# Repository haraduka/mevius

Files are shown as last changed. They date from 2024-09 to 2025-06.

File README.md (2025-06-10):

# MEVIUS
This repository includes the hardware and software components of "MEVIUS: A Quadruped Robot Easily Constructed through E-Commerce with Sheet Metal Welding and Machining."

Please refer to the following links for more information.
- [Project Page](https://haraduka.github.io/mevius-hardware)
- [arXiv](https://arxiv.org/abs/2409.14721)
- [YouTube](https://www.youtube.com/watch?v=XXJ4EK3Y4zQ)

# Hardware

You can find all the hardware components in the following link
- [Goodle Drive](https://drive.google.com/drive/folders/18i6CWtUG8fkY0rCcbjN5WiUYItjIX0WM?usp=sharing)

From the link of RUBIK LINK V2.0, please download the upper computer installation program and make all the motors MIT mode.
- [AK70-10](https://www.cubemars.com/goods-1031-AK70-10.html)
- [AK Serials Manual](https://www.cubemars.com/images/file/20241217/1734428582786471.pdf)
- [RUBIK LINK V2.0](https://www.cubemars.com/goods-1140-RUBIK+LINK+V20.html)
- Motor Order: FR(1-3) --> FL(4-6) --> BR(7-9) --> BL(10-12) / Proximal --> Distal
- Link Name: FR_scapula_link --> FR_thigh_link --> FR_calf_link
- Joint Name: FR_collar --> FR_hip --> FR_knee

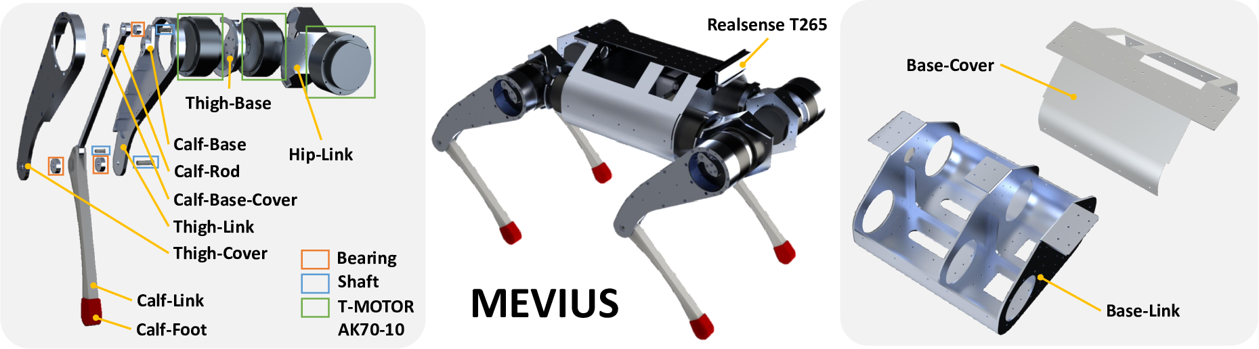
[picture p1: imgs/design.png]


# Software Dependencies
Please install the following dependencies.
- [ROS](https://www.ros.org/)
- [realsense-ros](https://github.com/IntelRealSense/realsense-ros/tree/ros1-legacy)
- [spacenav_node](https://wiki.ros.org/spacenav_node) # optional
- [virtual_joystick](https://github.com/aquahika/rqt_virtual_joystick) # optional
- [urdfdom-py](https://github.com/ros/urdf_parser_py)
- [legged_gym](https://github.com/leggedrobotics/legged_gym)

Please install the following python packages.
- bitstring
- pytorch
- scipy
- mujoco
- mujoco-python-viewer

# Build
```
mkdir -p ~/mevius_ws/src
cd ~/mevius_ws/src
git clone git@github.com:haraduka/mevius.git
cd ..
catkin build
source ~/mevius_ws/devel/setup.bash
```

# Reinforcement Learning
Caution: This policy is very simple and not so stable. Currently, it became very stable with a lot of improvement and will be uploaded soon.

```
# in legged_gym
git remote add haraduka git@github.com:haraduka/legged_gym.git
git fetch haraduka
git checkout haraduka/mevius

# train with two phases
# first phase
python3 legged_gym/scripts/train.py --task mevius
# second phase
# change the parameters in legged_gym/envs/mevius/mevius_config.py from "first" to "second"
# there are two parameters to change: commands.ranges and domain_rand.friction_range
python3 legged_gym/scripts/train.py --task mevius
python3 legged_gym/scripts/play.py --task mevius --load_run ( log_dir )
cp logs/flat_mevius/( log_dir )/exported/policies/policy_1.pt ../mevius/models/policy.pt

```

# Usage
Please test the installation by running the following command.
```
python3 scripts/mevius_utils.py
```
Please test the motors by running the following command.
```
./bin/can_setup.sh
python scripts/tmotor_test.py --ids 1 --task sense
```
Please test the real robot by running the following command.
```
# in the PC of MEVIUS
roscore
roslaunch realsense2_camera rs_t265.launch
./bin/can_setup.sh
python3 scripts/mevius_main.py

# in your local PC
roslaunch spacenav_node classic.launch

# Left Click: SITDOWN/STANDUP, Right Click: STANDUP/WALK

# if you want to simulate the robot in mujoco
python3 scripts/mevius_main.py --sim

# please press D to turn off every-step rendering in mujoco viewer
```

# Acknowledgements
- scripts/tmotor_lib.py is from [mini-cheetah-tmotor-python-can](https://github.com/dfki-ric-underactuated-lab/mini-cheetah-tmotor-python-can)
- scripts/isaacgym_torch_utils.py is from [IsaacGym](https://developer.nvidia.com/isaac-gym)
- scripts/legged_gym_math.py is from [LeggedGym](https://github.com/leggedrobotics/legged_gym)

# Citation
```
@inproceedings{kawaharazuka2024mevius,
  author={K. Kawaharazuka and S. Inoue and T. Suzuki and S. Yuzaki and S. Sawaguchi and K. Okada and M. Inaba},
  title={{MEVIUS: A Quadruped Robot Easily Constructed through E-Commerce with Sheet Metal Welding and Machining}},
  booktitle={Proceedings of the 2024 IEEE-RAS International Conference on Humanoid Robots},
  year=2024,
}
```

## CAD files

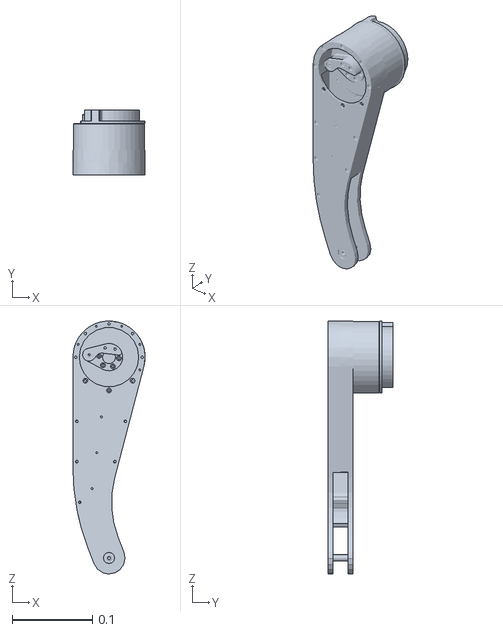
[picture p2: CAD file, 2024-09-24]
models/meshes/BR_thigh_link.STL
0.09 x 0.0811 x 0.315

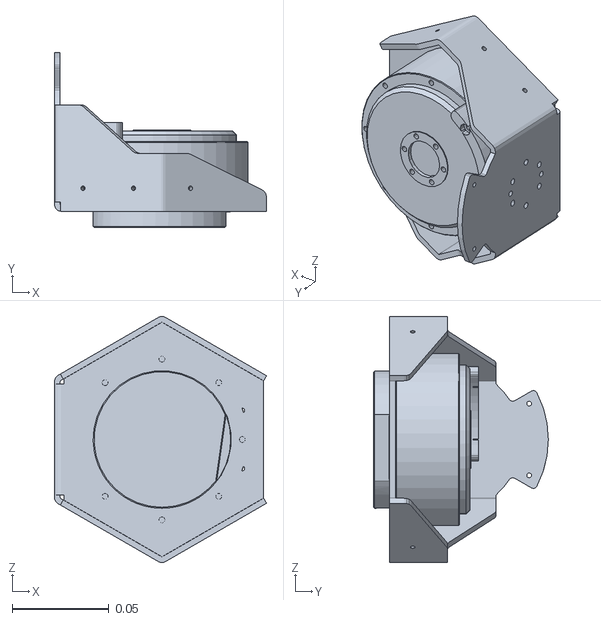
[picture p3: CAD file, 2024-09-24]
models/meshes/FL_scapula_link.STL
0.109 x 0.0902 x 0.127

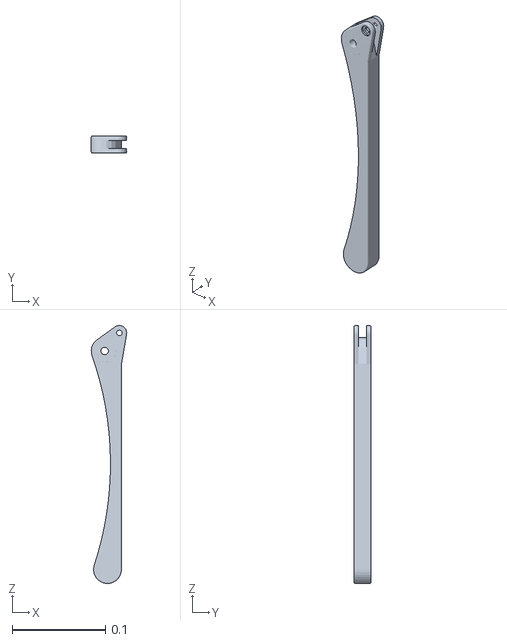
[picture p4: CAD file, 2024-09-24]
models/meshes/BL_calf_link.STL
0.0382 x 0.018 x 0.277

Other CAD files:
models/meshes/BL_thigh_link.STL
models/meshes/FR_scapula_link.STL
models/meshes/BR_scapula_link.STL
models/meshes/FR_thigh_link.STL
models/meshes/BL_scapula_link.STL
models/meshes/FL_thigh_link.STL

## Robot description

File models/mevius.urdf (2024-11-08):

<?xml version="1.0" encoding="utf-8"?>
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
<robot name="mevius">
  <link name="base_link">
    <inertial>
      <origin xyz="-0.00288686344144184 0.0 0.0628887711129525" rpy="0 0 0" />
      <mass value="8.0" />
      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
    </inertial>
    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
  </link>
  <link name="FR_scapula_link">
    <inertial>
      <origin xyz="0.0516252305401659 0.0119000363955649 0.000134643082608681" rpy="0 0 0" />
      <mass value="0.79238908220585" />
      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
    </inertial>
    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
  </link>
  <joint name="FR_collar" type="revolute">
    <origin xyz="0.16405000000001 -0.0720000000000002 0.056500000000002" rpy="0 0 0" />
    <parent link="base_link" />
    <child link="FR_scapula_link" />
    <axis xyz="1 0 0" />
    <limit lower="-0.7854" upper="0.7854" effort="25" velocity="310" />
  </joint>
  <link name="FR_thigh_link">
    <inertial>
      <origin xyz="-0.00458315732717235 -0.0450237251724228 -0.0462116341919131" rpy="0 0 0" />
      <mass value="1.28036049228712" />
      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
    </inertial>
    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
  </link>
  <joint name="FR_hip" type="revolute">
    <origin xyz="0.0555000000000021 -0.01205000000001 0" rpy="0 0 0" />
    <parent link="FR_scapula_link" />
    <child link="FR_thigh_link" />
    <axis xyz="0 1 0" />
    <limit lower="0.0" upper="1.5708" effort="25" velocity="310" />
  </joint>
  <link name="FR_calf_link">
    <inertial>
      <origin xyz="0.00539418153839358 5.12554836518131E-06 -0.108191288731219" rpy="0 0 0" />
      <mass value="0.101512760080133" />
      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
    </inertial>
    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
  </link>
  <joint name="FR_knee" type="revolute">
    <origin xyz="0 -0.06555000000001 -0.250000000000004" rpy="0 0 0" />
    <parent link="FR_thigh_link" />
    <child link="FR_calf_link" />
    <axis xyz="0 1 0" />
    <dynamics damping="0" friction="0"/>
    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
    <limit lower="-2.8745" upper="-1.08" effort="25" velocity="310" />
  </joint>
  <link name="FR_foot_link">
    <inertial>
      <origin xyz="0 0 0" rpy="0 0 0" />
      <mass value="0.05" />
      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
    </inertial>
    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
  </link>
  <joint name="FR_ankle_joint" type="fixed" dont_collapse="true">
    <origin xyz="0.003 0.0 -0.235" rpy="0 0 0"/>
    <parent link="FR_calf_link"/>
    <child link="FR_foot_link"/>
  </joint>

  <link name="FL_scapula_link">
    <inertial>
      <origin xyz="0.0516252305401659 -0.0119000363955649 0.000134643082608681" rpy="0 0 0" />
      <mass value="0.79238908220585" />
      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
    </inertial>
    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
  </link>
  <joint name="FL_collar" type="revolute">
    <origin xyz="0.16405000000001 0.0720000000000002 0.056500000000002" rpy="0 0 0" />
    <parent link="base_link" />
    <child link="FL_scapula_link" />
    <axis xyz="1 0 0" />
    <limit lower="-0.7854" upper="0.7854" effort="25" velocity="310" />
  </joint>
  <link name="FL_thigh_link">
    <inertial>
      <origin xyz="-0.00458315732717235 0.0450237251724228 -0.0462116341919131" rpy="0 0 0" />
      <mass value="1.28036049228712" />
      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
    </inertial>
    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
  </link>
  <joint name="FL_hip" type="revolute">
    <origin xyz="0.0555000000000021 0.01205000000001 0" rpy="0 0 0" />
    <parent link="FL_scapula_link" />
    <child link="FL_thigh_link" />
    <axis xyz="0 1 0" />
    <limit lower="0.0" upper="1.5708" effort="25" velocity="310" />
  </joint>
  <link name="FL_calf_link">
    <inertial>
      <origin xyz="0.00539418153839358 5.12554836518131E-06 -0.108191288731219" rpy="0 0 0" />
      <mass value="0.101512760080133" />
      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
    </inertial>
    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
  </link>
  <joint name="FL_knee" type="revolute">
    <origin xyz="0 0.06555000000001 -0.250000000000004" rpy="0 0 0" />
    <parent link="FL_thigh_link" />
    <child link="FL_calf_link" />
    <axis xyz="0 1 0" />
    <dynamics damping="0" friction="0"/>
    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
    <limit lower="-2.8745" upper="-1.08" effort="25" velocity="310" />
  </joint>
  <link name="FL_foot_link">
    <inertial>
      <origin xyz="0 0 0" rpy="0 0 0" />
      <mass value="0.05" />
      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
    </inertial>
    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
  </link>
  <joint name="FL_ankle_joint" type="fixed" dont_collapse="true">
    <origin xyz="0.003 0.0 -0.235" rpy="0 0 0"/>
    <parent link="FL_calf_link"/>
    <child link="FL_foot_link"/>
  </joint>
  <link name="BR_scapula_link">
    <inertial>
      <origin xyz="-0.051625 0.0119 -0.00013464" rpy="0 0 0" />
      <mass value="0.79239" />
      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
    </inertial>
    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
  </link>
  <joint name="BR_collar" type="revolute">
    <origin xyz="-0.16405000000001 -0.0719999999999995 0.0565000000000019" rpy="0 0 0" />
    <parent link="base_link" />
    <child link="BR_scapula_link" />
    <axis xyz="1 0 0" />
    <limit lower="-0.7854" upper="0.7854" effort="25" velocity="310" />
  </joint>
  <link name="BR_thigh_link">
    <inertial>
      <origin xyz="-0.0038406 -0.045024 -0.046019" rpy="0 0 0" />
      <mass value="1.28036049228712" />
      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
    </inertial>
    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
  </link>
  <joint name="BR_hip" type="revolute">
    <origin xyz="-0.0555000000000055 -0.01205000000001 0" rpy="0 0 0" />
    <parent link="BR_scapula_link" />
    <child link="BR_thigh_link" />
    <axis xyz="0 1 0" />
    <limit lower="0.0" upper="1.5708" effort="25" velocity="310" />
  </joint>
  <link name="BR_calf_link">
    <inertial>
      <origin xyz="0.00539418153839397 5.12554836515355E-06 -0.108191288731218" rpy="0 0 0" />
      <mass value="0.101512760080133" />
      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
    </inertial>
    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
  </link>
  <joint name="BR_knee" type="revolute">
    <origin xyz="0 -0.06555 -0.25" rpy="0 0 0" />
    <parent link="BR_thigh_link" />
    <child link="BR_calf_link" />
    <axis xyz="0 1 0" />
    <dynamics damping="0" friction="0"/>
    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
    <limit lower="-2.8745" upper="-1.08" effort="25" velocity="310" />
  </joint>
  <link name="BR_foot_link">
    <inertial>
      <origin xyz="0 0 0" rpy="0 0 0" />
      <mass value="0.05" />
      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
    </inertial>
    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
  </link>
  <joint name="BR_ankle_joint" type="fixed" dont_collapse="true">
    <origin xyz="0.003 0.0 -0.235" rpy="0 0 0"/>
    <parent link="BR_calf_link"/>
    <child link="BR_foot_link"/>
  </joint>
  <link name="BL_scapula_link">
    <inertial>
      <origin xyz="-0.0516252305401659 -0.0119000363955648 -0.000157365462420601" rpy="0 0 0" />
      <mass value="0.792389082205849" />
      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
    </inertial>
    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
  </link>
  <joint name="BL_collar" type="revolute">
    <origin xyz="-0.16405000000001 0.0719999999999999 0.0564999653300497" rpy="0 0 0" />
    <parent link="base_link" />
    <child link="BL_scapula_link" />
    <axis xyz="1 0 0" />
    <limit lower="-0.7854" upper="0.7854" effort="25" velocity="310" />
  </joint>
  <link name="BL_thigh_link">
    <inertial>
      <origin xyz="-0.00390161717030679 0.0450237251724227 -0.0460663202075131" rpy="0 0 0" />
      <mass value="1.28036049228712" />
      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
    </inertial>
    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
  </link>
  <joint name="BL_hip" type="revolute">
    <origin xyz="-0.0555000000000055 0.01205000000001 0" rpy="0 0 0" />
    <parent link="BL_scapula_link" />
    <child link="BL_thigh_link" />
    <axis xyz="0 1 0" />
    <limit lower="0.0" upper="1.5708" effort="25" velocity="310" />
  </joint>
  <link name="BL_calf_link">
    <inertial>
      <origin xyz="0.00539418153839397 5.12554836515355E-06 -0.108191288731218" rpy="0 0 0" />
      <mass value="0.101512760080133" />
      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
    </inertial>
    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
  </link>
  <joint name="BL_knee" type="revolute">
    <origin xyz="0 0.06555 -0.25" rpy="0 0 0" />
    <parent link="BL_thigh_link" />
    <child link="BL_calf_link" />
    <axis xyz="0 1 0" />
    <dynamics damping="0" friction="0"/>
    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
    <limit lower="-2.8745" upper="-1.08" effort="25" velocity="310" />
  </joint>
  <link name="BL_foot_link">
    <inertial>
      <origin xyz="0 0 0" rpy="0 0 0" />
      <mass value="0.05" />
      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
    </inertial>
    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
  </link>
  <joint name="BL_ankle_joint" type="fixed" dont_collapse="true">
    <origin xyz="0.003 0.0 -0.235" rpy="0 0 0"/>
    <parent link="BL_calf_link"/>
    <child link="BL_foot_link"/>
  </joint>
</robot>

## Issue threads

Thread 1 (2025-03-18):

Proposal for release of 3d-printable parts data in STEP format.

shiba-8ro, 2025-03-18:
The 3d-printable parts of MEVIUS are only available in STL format.
I propose to release them in STEP as well, for improvement.
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

haraduka, 2025-03-19:
Thank you for your proposal.
I released STEP files of 3d-printable parts in google drive.

Also, I newly added an assembled STEP file for easier reproduction.

Closed 2025-03-19.

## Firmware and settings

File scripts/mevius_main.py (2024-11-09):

import argparse
import os
import sys
import select
import time
import threading
import numpy as np

import rospy
from scipy.spatial.transform import Rotation
from std_msgs.msg import String, Float32MultiArray
from sensor_msgs.msg import Imu, Joy, JointState
from nav_msgs.msg import Odometry
from tmotor_lib import CanMotorController
from mevius.msg import MeviusLog
import mevius_utils
import parameters as P

# TODO add terminal display of thermometer, etc.

np.set_printoptions(precision=3)

class RobotState:
    def __init__(self, n_motor=12):
        self.angle = [0.0] * n_motor
        self.velocity = [0.0] * n_motor
        self.current = [0.0] * n_motor
        self.temperature = [0.0] * n_motor
        self.lock = threading.Lock()

class PeripheralState:
    def __init__(self):
        self.realsense_last_time = None
        self.body_vel = [0.0] * 3
        self.body_quat = [0.0] * 4
        self.body_gyro = [0.0] * 3
        self.body_acc = [0.0] * 3
        self.spacenav_enable = False
        self.spacenav = [0.0] * 8
        self.virtual_enable = False
        self.virtual = [0.0] * 4
        self.lock = threading.Lock()

class RobotCommand:
    def __init__(self, n_motor=12):
        self.angle = [0.0] * n_motor
        self.velocity = [0.0] * n_motor
        self.kp = []
        self.kd = []
        self.coef = 1.0
        for name in P.JOINT_NAME:
            for key in P.control.stiffness.keys():
                if key in name:
                    self.kp.append(P.control.stiffness[key]*self.coef)
                    self.kd.append(P.control.damping[key]*self.coef)
        assert len(self.kp) == n_motor
        assert len(self.kd) == n_motor
        self.torque = [0.0] * n_motor

        self.command = "STANDBY"
        self.initial_angle = [0.0] * n_motor
        self.final_angle = [0.0] * n_motor
        self.interpolating_time = 0.0
        self.remaining_time = 0.0
        self.initialized = False

        self.lock = threading.Lock()

################ function ##################

def command_callback(command, robot_state, robot_command):
    with robot_command.lock:
        prev_command = robot_command.command
        if not robot_command.initialized:
            pass
    if command == "STANDBY-STANDUP":
        with robot_command.lock:
            if robot_command.remaining_time < 0.1:
                if prev_command == "STANDBY":
                    robot_command.command = "STANDUP"
                    with robot_state.lock:
                        robot_command.initial_angle = robot_state.angle[:]
                        robot_command.final_angle = P.DEFAULT_ANGLE[:]
                        robot_command.interpolating_time = 3.0
                        robot_command.remaining_time = robot_command.interpolating_time
                elif prev_command == "STANDUP":
                    robot_command.command = "STANDBY"
                    with robot_state.lock:
                        robot_command.initial_angle = robot_state.angle[:]
                        robot_command.final_angle = P.STANDBY_ANGLE[:]
                        robot_command.interpolating_time = 3.0
                        robot_command.remaining_time = robot_command.interpolating_time
    elif command == "STANDUP-WALK":
        with robot_command.lock:
            if robot_command.remaining_time < 0.1:
                if prev_command == "STANDUP":
                    robot_command.command = "WALK"
                    robot_command.interpolating_time = 3.0
                    robot_command.remaining_time = robot_command.interpolating_time
                elif prev_command == "WALK":
                    robot_command.command = "STANDUP"
                    with robot_state.lock:
                        robot_command.initial_angle = robot_state.angle[:]
                        robot_command.final_angle = P.DEFAULT_ANGLE[:]
                        robot_command.interpolating_time = 3.0
                        robot_command.remaining_time = robot_command.interpolating_time
    elif command == "STANDBY":
        with robot_command.lock:
            robot_command.command = "STANDBY"
            with robot_state.lock:
                robot_command.initial_angle = robot_state.angle[:]
                robot_command.final_angle = P.STANDBY_ANGLE[:]
                robot_command.interpolating_time = 3.0
                robot_command.remaining_time = robot_command.interpolating_time
    elif command == "STANDUP":
            robot_command.command = "STANDUP"
            with robot_state.lock:
                robot_command.initial_angle = robot_state.angle[:]
                robot_command.final_angle = P.DEFAULT_ANGLE[:]
                robot_command.interpolating_time = 3.0
                robot_command.remaining_time = robot_command.interpolating_time
    elif command == "DEBUG":
            robot_command.command = "DEBUG"
            with robot_state.lock:
                robot_command.initial_angle = robot_state.angle[:]
                robot_command.final_angle = P.DEBUG_ANGLE[:]
                robot_command.interpolating_time = 3.0
                robot_command.remaining_time = robot_command.interpolating_time
    elif prev_command == "STANDUP" and command == "WALK":
            robot_command.command = "WALK"

    with robot_command.lock:
        print("Command changed from {} to {}".format(prev_command, robot_command.command))

def realsense_vel_callback(msg, params):
    peripherals_state = params
    with peripherals_state.lock:
        peripherals_state.body_vel = [msg.twist.twist.linear.x, msg.twist.twist.linear.y, msg.twist.twist.linear.z]
        # get odom quat
        peripherals_state.body_quat = [msg.pose.pose.orientation.x, msg.pose.pose.orientation.y, msg.pose.pose.orientation.z, msg.pose.pose.orientation.w]
        peripherals_state.realsense_last_time = time.time()

def realsense_gyro_callback(msg, params):
    peripherals_state = params
    with peripherals_state.lock:
        # peripherals_state.body_gyro = [msg.angular_velocity.x, msg.angular_velocity.y, msg.angular_velocity.z]
        # for realsenes arrangement
        peripherals_state.body_gyro = [msg.angular_velocity.z, msg.angular_velocity.x, msg.angular_velocity.y]

def realsense_acc_callback(msg, params):
    peripherals_state = params
    with peripherals_state.lock:
        # peripherals_state.body_acc = [msg.linear_acceleration.x, msg.linear_acceleration.y, -msg.linear_acceleration.z]
        # for realsenes arrangement
        peripherals_state.body_acc = [msg.linear_acceleration.z, msg.linear_acceleration.x, msg.linear_acceleration.y]

def virtual_joy_callback(msg, params):
    peripherals_state = params
    with peripherals_state.lock:
        peripherals_state.virtual_enable = True
        peripherals_state.virtual = [msg.axes[0], msg.axes[1], msg.buttons[0], msg.buttons[1]]
        one_pushed = peripherals_state.virtual[2]
        two_pushed = peripherals_state.virtual[3]

    if one_pushed == 1:
        command_callback("STANDBY-STANDUP", robot_state, robot_command)
    elif two_pushed == 1:
        command_callback("STANDUP-WALK", robot_state, robot_command)

def ros_command_callback(msg, params):
    robot_state, robot_command = params
    print("Received ROS Command: {}".format(msg.data))
    command_callback(msg.data, robot_state, robot_command)

def spacenav_joy_callback(msg, params):
    peripherals_state = params
    with peripherals_state.lock:
        peripherals_state.spacenav_enable = True
        peripherals_state.spacenav = [msg.axes[0], msg.axes[1], msg.axes[2], msg.axes[3], msg.axes[4], msg.axes[5], msg.buttons[0], msg.buttons[1]]
        left_pushed = peripherals_state.spacenav[6]
        right_pushed = peripherals_state.spacenav[7]

    if left_pushed == 1:
        command_callback("STANDBY-STANDUP", robot_state, robot_command)
    elif right_pushed == 1:
        command_callback("STANDUP-WALK", robot_state, robot_command)

def main_controller(robot_state, robot_command, peripherals_state):
    policy_path = os.path.join(os.path.dirname(__file__), "../models/policy.pt")
    policy = mevius_utils.read_torch_policy(policy_path).to("cpu")

    urdf_fullpath = os.path.join(os.path.dirname(__file__), "../models/mevius.urdf")
    joint_params = mevius_utils.get_urdf_joint_params(urdf_fullpath, P.JOINT_NAME)

    is_safe = True
    last_actions = [0.0] * 12 # TODO initialize

    rate = rospy.Rate(P.CONTROL_HZ)
    while not rospy.is_shutdown():
        with robot_command.lock:
            command = robot_command.command
        if command in ["STANDBY", "STANDUP", "DEBUG"]:
            with robot_command.lock:
                robot_command.remaining_time -= 1.0/P.CONTROL_HZ
                robot_command.remaining_time = max(0, robot_command.remaining_time)
                if robot_command.remaining_time <= 0:
                    pass
                else:
                    ratio = 1 - robot_command.remaining_time / robot_command.interpolating_time
                    robot_command.angle = [a + (b-a)*ratio for a, b in zip(robot_command.initial_angle, robot_command.final_angle)]
        elif command in ["WALK"]:
            with robot_command.lock:
                robot_command.remaining_time -= 1.0/P.CONTROL_HZ
                robot_command.remaining_time = max(0, robot_command.remaining_time)

            with peripherals_state.lock:
                base_quat = peripherals_state.body_quat[:]
                base_lin_vel = peripherals_state.body_vel[:]
                base_ang_vel = peripherals_state.body_gyro[:]

                ranges = P.commands.ranges
                coefs = [ranges.lin_vel_x[1], ranges.lin_vel_y[1], ranges.ang_vel_yaw[1], ranges.heading[1]]
                if peripherals_state.spacenav_enable:
                    nav = peripherals_state.spacenav[:]
                    max_command = 0.6835
                    commands_ = [nav[0], nav[1], nav[5], nav[5]]
                    commands = [[min(max(-coef, coef * command / max_command), coef) for coef, command in zip(coefs, commands_)]]
                elif peripherals_state.virtual_enable:
                    nav = peripherals_state.virtual[:]
                    max_command = 1.0
                    commands_ = [nav[1], nav[0], 0, 0]
                    commands = [[min(max(-coef, coef * command / max_command), coef) for coef, command in zip(coefs, commands_)]]
                else:
                    commands = torch.tensor([[0.0, 0.0, 0.0, 0.0]], dtype=torch.float, requires_grad=False)

        # for safety
        if command in ["WALK"]:
            # no realsense
            with peripherals_state.lock:
                if peripherals_state.realsense_last_time is None:
                    is_safe = False
                    print("No Connection to Realsense. PD gains become 0.")
                if (peripherals_state.realsense_last_time is not None) and (time.time() - peripherals_state.realsense_last_time > 0.1):
                    print("Realsense data is too old. PD gains become 0.")
                    is_safe = False
            # falling down
            if is_safe and (Rotation.from_quat(base_quat).as_matrix()[2, 2] < 0.6):
                is_safe = False
                print("Robot is almost fell down. PD gains become 0.")

            if not is_safe:
                print("Robot is not safe. Please reboot the robot.")
                with robot_command.lock:
                    robot_command.kp = [0.0] * 12
                    robot_command.kd = [0.0] * 12
                    with robot_state.lock:
                        robot_command.angle = robot_state.angle[:]
                rate.sleep()
                continue


        if command in ["WALK"]:
            with robot_state.lock:
                dof_pos = robot_state.angle[:]
                dof_vel = robot_state.velocity[:]
            # print(base_quat, base_lin_vel, base_ang_vel, commands, dof_pos, dof_vel, last_actions)
            obs = mevius_utils.get_policy_observation(base_quat, base_lin_vel, base_ang_vel, commands, dof_pos, dof_vel, last_actions)
            actions = mevius_utils.get_policy_output(policy, obs)
            scaled_actions = P.control.action_scale * actions

        if command in ["WALK"]:
            ref_angle = [a + b for a, b in zip(scaled_actions, P.DEFAULT_ANGLE[:])]
            with robot_state.lock:
                for i in range(len(ref_angle)):
                    if robot_state.angle[i]  < joint_params[i][0] or robot_state.angle[i] > joint_params[i][1]:
                        ref_angle[i] = max(joint_params[i][0]+0.1, min(ref_angle[i], joint_params[i][1]-0.1))
                        print("# Joint {} out of range: {:.3f}".format(P.JOINT_NAME[i], robot_state.angle[i]))
            with robot_command.lock:
                robot_command.angle = ref_angle

            last_actions = actions[:]
        # with peripherals_state.lock:
        #     print("Body Velocity: {}".format(peripherals_state.body_vel))
        #     print("Body Gyro: {}".format(peripherals_state.body_gyro))
        #     print("Body Acc: {}".format(peripherals_state.body_acc))

        rate.sleep()
        # time.sleep(1)

def can_communication(robot_state, robot_command, peripherals_state):
    device = "can0"
    motor_type = "AK70_10_V1p1"
    n_motor = 12
    motors = [None]*n_motor
    for i in range(n_motor):
        motors[i] = CanMotorController("can0", P.CAN_ID[i], motor_type=motor_type, motor_dir=P.MOTOR_DIR[i])

    print("Enabling Motors...")
    for i, motor in enumerate(motors):
        pos, vel, cur, tem = motor.enable_motor()
        print("Enabling Motor {} [Status] Pos: {:.3f}, Vel: {:.3f}, Cur: {:.3f}, Temp: {:.3f}".format(P.JOINT_NAME[i], pos, vel, cur, tem))
        with robot_state.lock:
            robot_state.angle[i] = pos
            robot_state.velocity[i] = vel
            robot_state.current[i] = cur
            robot_state.temperature[i] = tem

    state_pub = rospy.Publisher("mevius_log", MeviusLog, queue_size=2)
    jointstate_pub = rospy.Publisher("joint_states", JointState, queue_size=2)

    print("Setting Initial Offset...")
    for i, motor in enumerate(motors):
        motor.set_angle_offset(P.STANDBY_ANGLE[i], deg=False)
        # motor.set_angle_range(joint_params[i][0], joint_params[i][1], deg=False)

    with robot_state.lock:
        robot_state.angle = P.STANDBY_ANGLE[:]

    with robot_command.lock:
        robot_command.command = "STANDBY"
        robot_command.angle = P.STANDBY_ANGLE[:]
        robot_command.initial_angle = P.STANDBY_ANGLE[:]
        robot_command.final_angle = P.STANDBY_ANGLE[:]
        robot_command.interpolating_time = 3.0
        robot_command.remaining_time = robot_command.interpolating_time
        robot_command.initialized = True

    rate = rospy.Rate(P.CAN_HZ)

    error_count = [0]*12
    while not rospy.is_shutdown():
        start_time = time.time()
        msg = MeviusLog()
        msg.header.stamp = rospy.Time.now()

        jointstate_msg = JointState()
        jointstate_msg.header.stamp = rospy.Time.now()

        with robot_command.lock:
            ref_angle = robot_command.angle[:]
            ref_velocity = robot_command.velocity[:]
            ref_kp = robot_command.kp[:]
            ref_kd = robot_command.kd[:]
            ref_torque = robot_command.torque[:]

        n_motor = 12
        pos_list = [0]*n_motor
        vel_list = [0]*n_motor
        cur_list = [0]*n_motor
        tem_list = [0]*n_motor
        for i, motor in enumerate(motors):
            try:
                pos, vel, cur, tem = motor.send_rad_command(ref_angle[i], ref_velocity[i], ref_kp[i], ref_kd[i], ref_torque[i])
            except:
                error_count[i] += 1
                print("# Can Reciver is Failed for {}, ({})".format(P.JOINT_NAME[i], error_count[i]))
                continue
            pos_list[i] = pos
            vel_list[i] = vel
            cur_list[i] = cur
            tem_list[i] = tem

        with robot_state.lock:
            robot_state.angle = pos_list
            robot_state.velocity = vel_list
            robot_state.current = cur_list
            robot_state.temperature = tem_list

        jointstate_msg.name = P.JOINT_NAME
        jointstate_msg.position = pos_list
        jointstate_msg.velocity = vel_list
        jointstate_msg.effort = cur_list
        jointstate_pub.publish(jointstate_msg)

        msg.angle = pos_list
        msg.velocity = vel_list
        msg.current = cur_list
        msg.temperature = tem_list

        with peripherals_state.lock:
            msg.body_vel = peripherals_state.body_vel[:]
            msg.body_quat = peripherals_state.body_quat[:]
            msg.body_gyro = peripherals_state.body_gyro[:]
            msg.body_acc = peripherals_state.body_acc[:]

        msg.ref_angle = ref_angle
        msg.ref_velocity = ref_velocity
        msg.ref_kp = ref_kp
        msg.ref_kd = ref_kd
        msg.ref_torque = ref_torque

        state_pub.publish(msg)

        # rate.sleep()
        end_time = time.time()
        if end_time - start_time < 1.0/P.CAN_HZ:
            time.sleep(1.0/P.CAN_HZ - (end_time - start_time))
            # end_time = time.time()
            # print(end_time-start_time)
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

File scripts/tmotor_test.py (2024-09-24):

import argparse
import sys
import select
import time
import rospy
import numpy as np
from tmotor_lib import CanMotorController

def setZeroPosition(motor):
    pos, _, _ = motor.set_zero_position()
    while abs(np.rad2deg(pos)) > 0.5:
        pos, vel, cur = motor.set_zero_position()
        print("Position: {}, Velocity: {}, Torque: {}".format(np.rad2deg(pos), np.rad2deg(vel), cur))


def main():
    parser = argparse.ArgumentParser()
    parser.add_argument("--device", '-d', type=str, default="can0", help="can interface name")
    parser.add_argument("--ids", '-i', type=int, nargs="+", default=None, help="motor ids to control")
    parser.add_argument("--motor_type", type=str, default="AK70_10_V1p1", help="motor type")
    parser.add_argument("--task", '-t', type=str, default="sense", help="[pos, sense, bilateral, real, mevius]")
    parser.add_argument("--value", '-v', type=int, default=None, help="value used for task")
    parser.add_argument("--kp", type=float, default=3.0, help="p gain for position control")
    parser.add_argument("--kd", type=float, default=1.0, help="d gain for position control")
    parser.add_argument("--hz", type=int, default=1000, help="hz to control motor")
    parser.add_argument("--time", type=float, default=3.0, help="time to control [sec]")
    args = parser.parse_args()

    print("# using Socket {} for can communication".format(args.device))
    print("# motor ids: {}".format(args.ids))
    assert args.ids is not None, "please input motor ids"
    if args.task == "bilateral":
        assert len(args.ids) == 2, "please input two motor ids for bilateral control"

    ids = args.ids
    motors = {}
    for id in ids:
        motor_dir = 1
        if args.task == "mevius":
            if id in [1, 4, 5, 6, 11, 12]:
                motor_dir = -1
        motors[id] = CanMotorController(args.device, id, motor_dir=motor_dir, motor_type=args.motor_type)

    print("Enabling Motors..")
    for motor_id, motor_controller in motors.items():
        pos, vel, cur, tem = motor_controller.enable_motor()
        print("Motor {} Status: Pos: {}, Vel: {}, Torque: {}, Temp: {}".format(motor_id, pos, vel, cur, tem))

    time.sleep(1)

    rospy.init_node("tmotor_test")
    rate = rospy.Rate(args.hz)

    pos_vec = []
    vel_vec = []
    cur_vec = []
    tem_vec = []
    for motor_id, motor_controller in motors.items():
        pos, vel, cur, tem = motor_controller.send_deg_command(0, 0, 0.0, 0.0, 0)
        pos_vec.append(pos)
        vel_vec.append(vel)
        cur_vec.append(cur)
        tem_vec.append(tem)

    start_time = time.time()

    if args.task == "pos":
        for deg in np.linspace(0.0, 360.0, int(args.time*args.hz/len(args.ids))):
            for motor_id, motor_controller in motors.items():
                pos, vel, cur, tem = motor_controller.send_deg_command(deg, 0, args.kp, args.kd, 0)
                print("Moving Motor {} Position: {}, Velocity: {}, Torque: {}, Temp: {}".format(motor_id, pos, vel, cur, tem))
            rate.sleep()
            end_time = time.time()
            print("Time taken: {}".format(end_time - start_time))
            start_time = end_time
    elif args.task == "sense":
        while not rospy.is_shutdown():
            for i, (motor_id, motor_controller) in enumerate(motors.items()):
                pos, vel, cur, tem = motor_controller.send_deg_command(0, 0, 0.0, 0.0, 0)
                print("Moving Motor {} Position: {}, Velocity: {}, Torque: {}, Temp: {}".format(motor_id, pos, vel, cur, tem))
            rate.sleep()
            # if enter is pressed, break with non-blocking
            if select.select([sys.stdin,],[],[],0.0)[0]:
                input_char = sys.stdin.read(1)
                if input_char == '\n':
                    break
    elif args.task == "bilateral":
        while not rospy.is_shutdown():
            for i, (motor_id, motor_controller) in enumerate(motors.items()):
                 command_cur = max(-4.0, min(0.02*(pos_vec[(i+1)%2]-pos_vec[i])+0.01*(vel_vec[(i+1)%2]-vel_vec[i]), 4.0))
                 pos, vel, cur, tem = motor_controller.send_deg_command(0, 0, 0.0, 0.0, command_cur)
                 print("Moving Motor {} Position: {}, Velocity: {}, Torque: {}, Temp: {}".format(motor_id, pos, vel, cur, tem))
                 pos_vec[i] = pos
                 vel_vec[i] = vel
                 cur_vec[i] = cur
                 tem_vec[i] = tem
            end_time = time.time()
            print("Time taken: {}".format(end_time - start_time))
            start_time = end_time
            rate.sleep()
            # if enter is pressed, break with non-blocking
            if select.select([sys.stdin,],[],[],0.0)[0]:
                input_char = sys.stdin.read(1)
                if input_char == '\n':
                    break
    elif args.task == "real":
        initial_pos = []
        for motor_id, motor_controller in motors.items():
            motor_controller.set_angle_range(-90, 90, deg=True)
            motor_controller.set_angle_offset(45, deg=True)
            initial_pos.append(motor_controller.current_pos)
        for deg in np.linspace(0.0, 360.0, int(args.time*args.hz/len(args.ids))):
            for i, (motor_id, motor_controller) in enumerate(motors.items()):
                pos, vel, cur, tem = motor_controller.send_deg_command(initial_pos[i]+deg, 0, args.kp, args.kd, 0)
                print("Moving Motor {} Position: {}, Velocity: {}, Torque: {}, Temp: {}".format(motor_id, pos, vel, cur, tem))
            rate.sleep()
            end_time = time.time()
            print("Time taken: {}".format(end_time - start_time))
        for deg in np.linspace(0.0, -360.0, int(args.time*args.hz/len(args.ids))):
            for i, (motor_id, motor_controller) in enumerate(motors.items()):
                pos, vel, cur, tem = motor_controller.send_deg_command(initial_pos[i]+deg, 0, args.kp, args.kd, 0)
                print("Moving Motor {} Position: {}, Velocity: {}, Torque: {}, Temp: {}".format(motor_id, pos, vel, cur, tem))
            rate.sleep()
            end_time = time.time()
            print("Time taken: {}".format(end_time - start_time))
            start_time = end_time
        print("end")
    elif args.task == "mevius":
        initial_offset = [-0.1, 1.4, -2.9, 0.1, 1.4, -2.9, -0.1, 1.4, -2.9, 0.1, 1.4, -2.9]
        final_angle = [0.0, 0.8, -1.6, 0.0, 0.8, -1.6, -0.0, 0.8, -1.6, 0.0, 0.8, -1.6]
        for i, (motor_id, motor_controller) in enumerate(motors.items()):
            motor_controller.set_angle_offset(initial_offset[motor_id-1], deg=False)
        move_time = 5.0
        for deg_rate in np.linspace(0.0, 1.0, int(move_time*args.hz/len(args.ids))):
            for i, (motor_id, motor_controller) in enumerate(motors.items()):
                command = initial_offset[motor_id-1]+deg_rate*(final_angle[motor_id-1]-initial_offset[motor_id-1])
                pos, vel, cur, tem = motor_controller.send_rad_command(command, 0, args.kp, args.kd, 0)
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

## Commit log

2024-11-08 add simulator
    [mevius.urdf]
2024-11-09 add motor information
